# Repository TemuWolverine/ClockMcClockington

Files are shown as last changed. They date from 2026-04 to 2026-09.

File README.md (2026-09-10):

# ClockMcClockington
I currently have some “Lenovo Smart Clock Essentials” around the house, but they’ll need to be returned to the original owner soon. Essentially they’re just a segment display with some smarts and a microphone for Google Home.

I’m no fan of voice assistance, so the microphone has been off, meaning they don’t provide much real world value for me other than a clock and that should be easy enough to replicate with an ESP32 and ESPHome.

Since all of the smarts in my house run off Home Assistant (HA), I want this clock to be able to interact with HA. Specifically, I want some buttons that can then trigger other things in the house, such as “shut down all the lights”, or “volume up/down” for the bedroom Sonos speakers. That way I don’t need to have my phone on.

## BoM
| Part | Quantity | Note |
| -----| --- | ---- |
| [ESP32-S3 Nano](https://s.click.aliexpress.com/e/_c4kUQqIB) | 1 | If you're using the ClockMcClockington PCB, it is designed for this specific ESP32. Otherwise, any S3 with 2MB of PSRAM should be fine |
| [5mm Tactile switches](https://s.click.aliexpress.com/e/_c4DqcA55) | 4 | |
| [GL5516 LDR Photoresistor](https://s.click.aliexpress.com/e/_c41f2RgX) | 1 | |
| [INMP441 Microphone](https://www.aliexpress.com/item/1005006090551057.html) | 1 | |
| [MAX98357a amplifier](https://www.aliexpress.com/item/1005007003802663.html) | 1 | |
| Speaker | 1 | |
|  0.1uf ceramic capacitor | 2| Decoupling, through-hole|
| 10k ohm resistor | 1 | Through-hole|
| ClockMcClockington PCB | 1 | Optional|

## Software
The ESPHome configuration is available as the [yaml file](https://github.com/TemuWolverine/ClockMcClockington/blob/main/clock.yaml), or as a [binary you can flash directly from your browser](https://temuwolverine.github.io/ClockMcClockington/)

### Setup
The temperature information is fetched from Home Assistant. You'll need to have the sensor preconfigured.

* Setup a template sensor
* Navigate (in Home Assistant) to Settings > Devices & Services > Helpers
* Create Helper (bottom right corner) > Template > Sensor
* Two fields are required, the name and the state. Name must be `clock_temp`
* Set the state to `{{ states("sensor.myweathersensor_temperature")}}`
  The other fields are entirely optional, but can make presentation in HomeAssistant clearer 

Alternatively, you can edit the YAML, change `weatherSensor : sensor.clock_temp` to `weatherSensor : sensor.sensor.myweathersensor_temperature`

### Automations
The way ESPHome exposes hardware buttons to Home Assistant is a bit funky (or I'm an idiot and have done it wrong) - they're exposed as generic events rather than 'click'.

ClockMcClockington sends out `esphome.<name>.clock_button_pressed`, where name will start with 'clockmcclockington' plus the MAC of the device. The event data will be one, two, three or four. Currently long press and double click are not implemented. 
```yaml
alias: btnOne
description: ""
triggers:
  - trigger: event
    event_data:
      button: one
    event_type: esphome.clockmcclockingtonred.clock_button_pressed
conditions: []
actions:
  - action: light.toggle
    metadata: {}
    target:
      area_id: study
    data: {}
mode: single
```

## Shell
TODO: 

## Circuit
The Kicad project for the circuit design is available under the [/circuit](https://github.com/TemuWolverine/ClockMcClockington/tree/main/circuit) folder


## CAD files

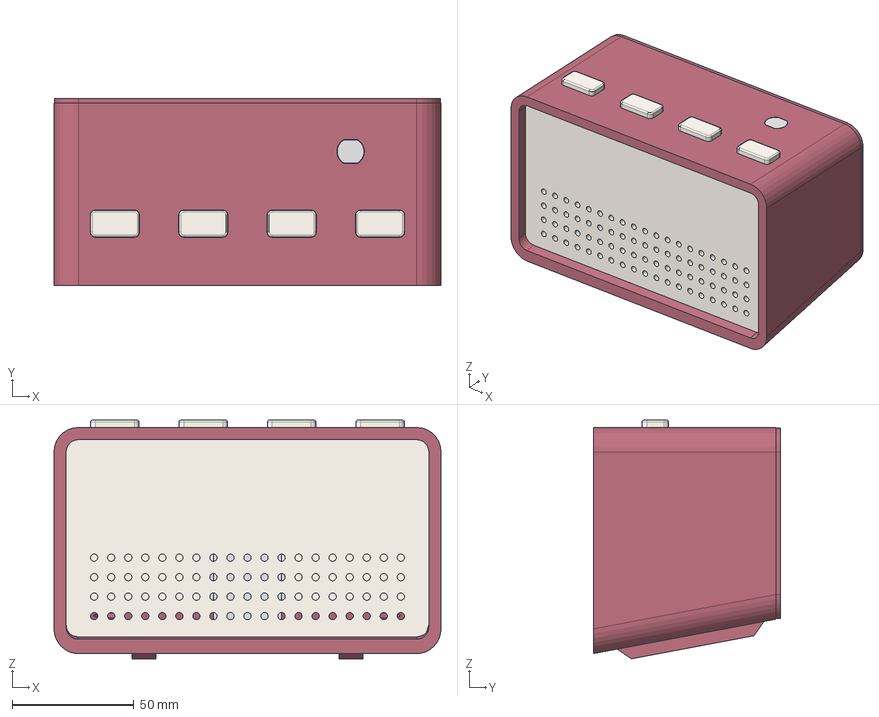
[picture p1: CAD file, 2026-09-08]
models/ClockMcClockington.step
159.0 x 77.0 x 98.0 mm
Outside
Button x 4
Back Panel
LDR Cap
Speaker
PCB
90 5xHeader Pins
1088AS x 4
8x female rounded header x 8
MAX7219--3DModel-STEP-56544 x 4
PinSocket_1x05_P2.54mm_Vertical
R_Axial_DIN0204_L3.6mm_D1.6mm_P2.54mm_Vertical
PinHeader_1x07_P2.54mm_Vertical
C_Disc_D8.0mm_W2.5mm_P5.00mm x 2
SW_PUSH_6mm_H5mm x 4
R_LDR_4.9x4.2mm_P2.54mm_Vertical
Clock_silkscreen
Clock_silkscreen_1
Clock_PCB

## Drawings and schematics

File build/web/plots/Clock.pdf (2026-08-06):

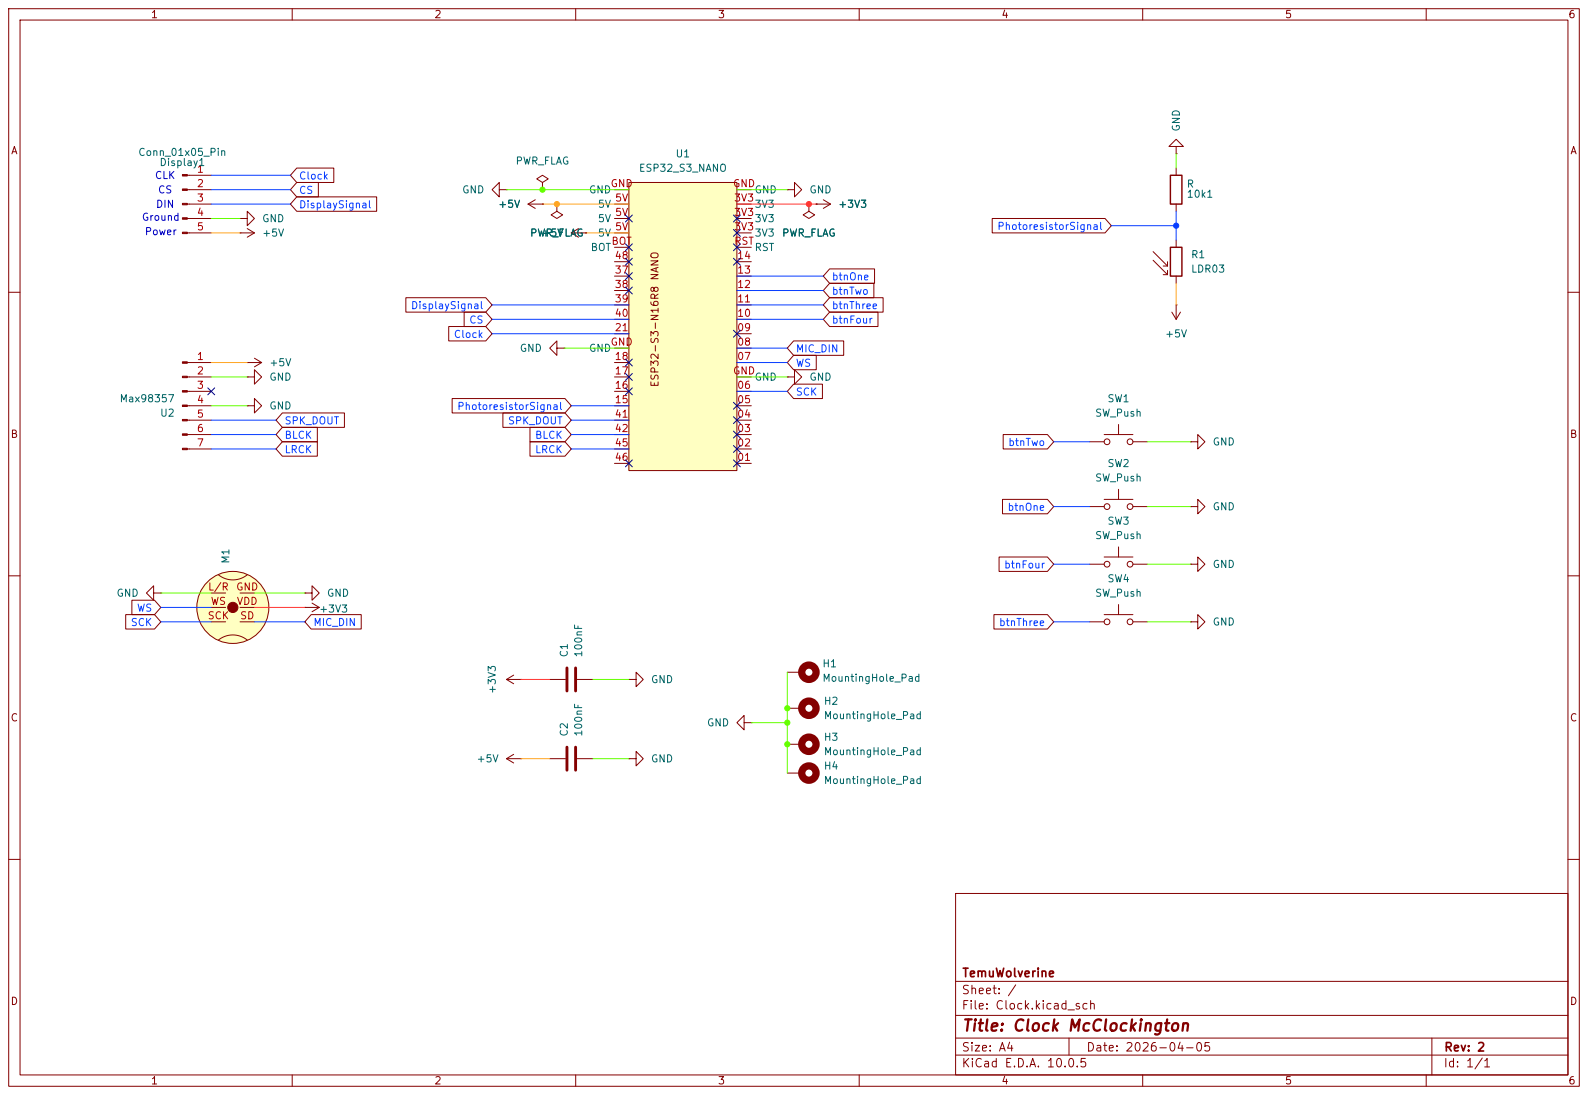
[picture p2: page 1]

Size: A4 | Rev: 2
KiCad E.D.A. 10.0.5 | Id: 1/1

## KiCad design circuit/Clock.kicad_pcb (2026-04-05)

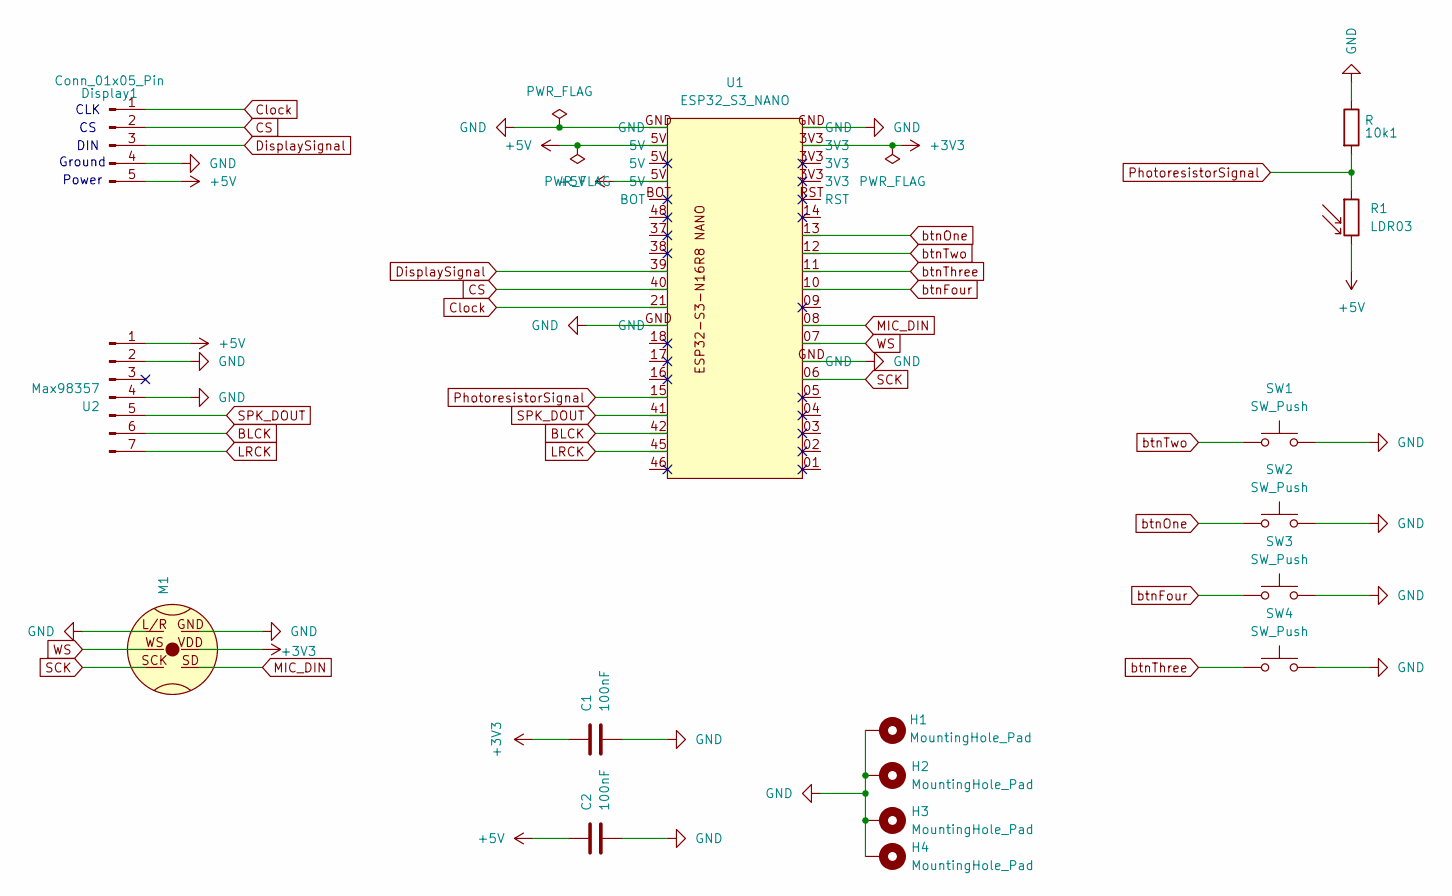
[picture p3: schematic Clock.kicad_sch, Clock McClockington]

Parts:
10k1: R; R_Axial_DIN0204_L3.6mm_D1.6mm_P2.54mm_Vertical
C1, C2: 100nF; C_Disc_D8.0mm_W2.5mm_P5.00mm
Display1: Conn_01x05_Pin; PinSocket_1x05_P2.54mm_Vertical
H1, H2, H3, H4: MountingHole_Pad; MountingHole_3.2mm_M3_Pad
M1: INMP441
R1: LDR03; R_LDR_4.9x4.2mm_P2.54mm_Vertical
SW1, SW2, SW3, SW4: SW_Push; SW_PUSH_6mm_H5mm
U1: ESP32_S3_NANO
U2: Max98357; PinHeader_1x07_P2.54mm_Vertical

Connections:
+3V3: C1.1, M1.VDD, U1.3V3
+5V: C2.1, Display1.5, R1.2, U1.5V, U2.1
BLCK: U1.42, U2.6
CS: Display1.2, U1.40
Clock: Display1.1, U1.21
DisplaySignal: Display1.3, U1.39
GND: 10k1.1, C1.2, C2.2, Display1.4, H1.1 (1_1), H2.1 (1_1), H3.1 (1_1), H4.1 (1_1), M1.GND, M1.L/R, SW1.2, SW2.2, SW3.2, SW4.2, U1.GND, U2.2, U2.4
LRCK: U1.45, U2.7
MIC_DIN: M1.SD, U1.08
PhotoresistorSignal: 10k1.2, R1.1, U1.15
SCK: M1.SCK, U1.06
SPK_DOUT: U1.41, U2.5
WS: M1.WS, U1.07
btnFour: SW3.1, U1.10
btnOne: SW2.1, U1.13
btnThree: SW4.1, U1.11
btnTwo: SW1.1, U1.12

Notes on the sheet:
CLK
Power
DIN
Ground

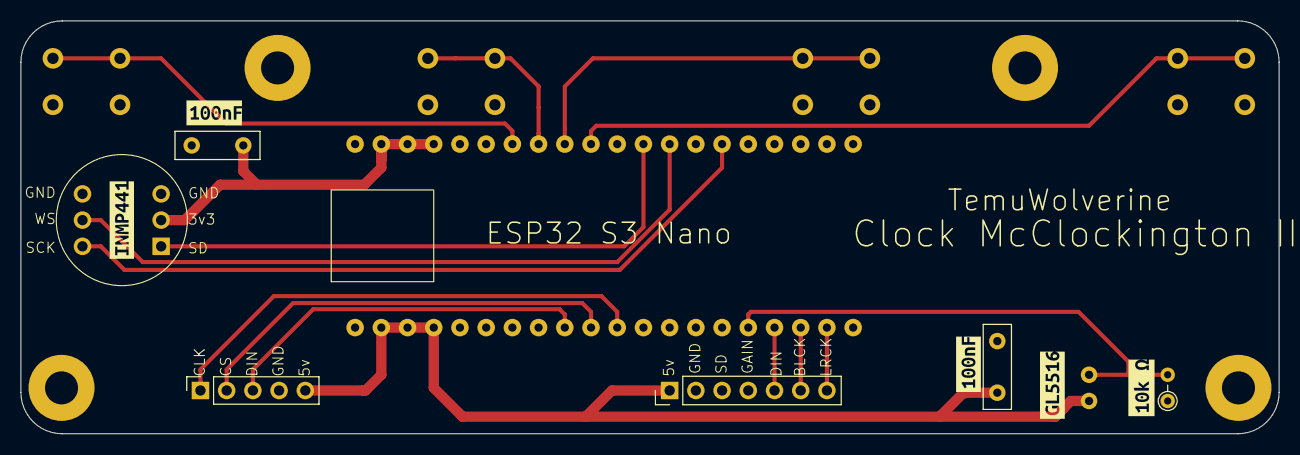
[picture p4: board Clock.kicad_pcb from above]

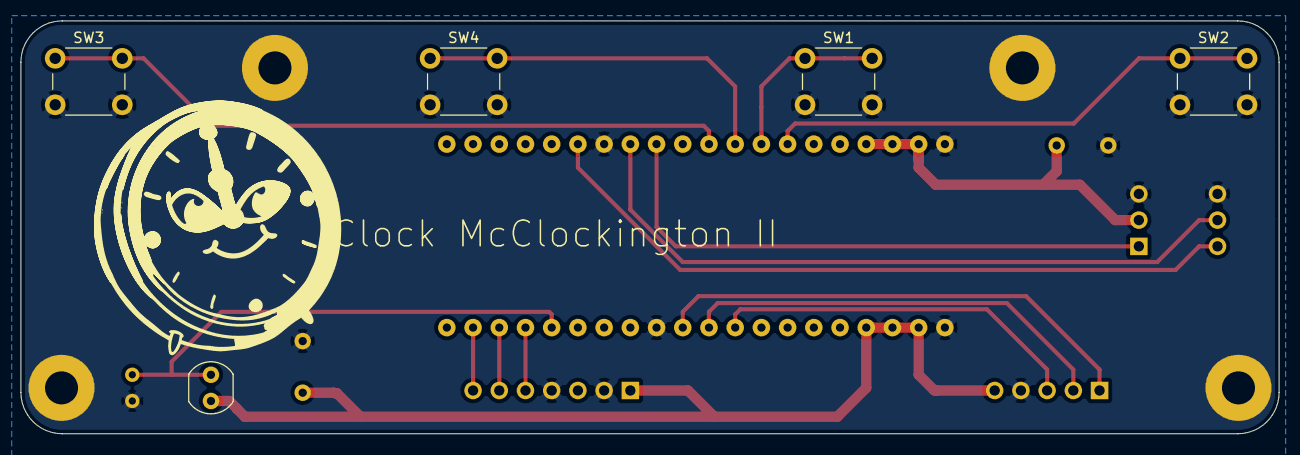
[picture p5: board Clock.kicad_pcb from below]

Board: 2 copper layers, 121.9 x 40.0 mm, 21 parts (5 on the bottom side), 17 nets.

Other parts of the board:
kibuzzard-69B74AE8: G***; kibuzzard-69B74AE8
kibuzzard-69B74AF7: G***; kibuzzard-69B74AF7
kibuzzard-69B74B07: G***; kibuzzard-69B74B07
kibuzzard-69B74B24, kibuzzard-69B74B24#2: G***; kibuzzard-69B74B24

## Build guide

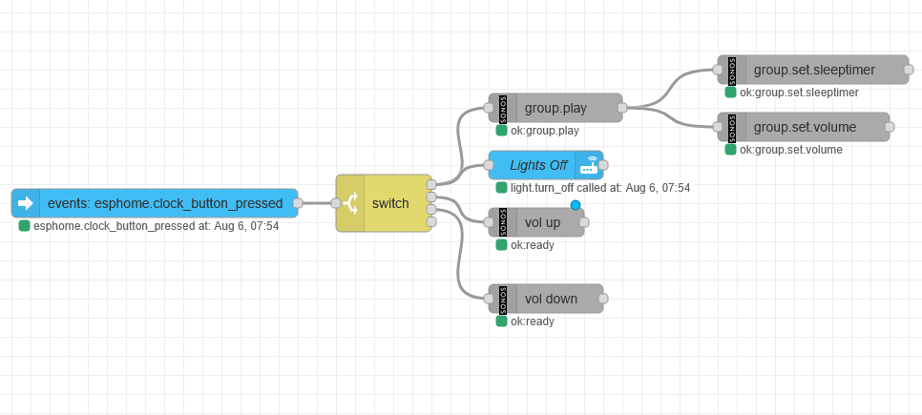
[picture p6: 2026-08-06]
build/web/assets/images/nodered.png

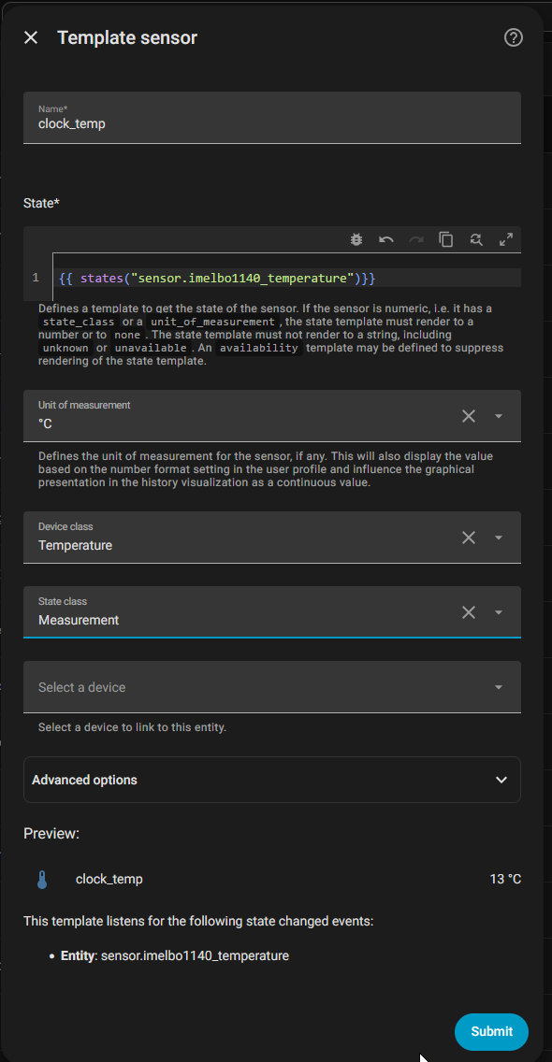
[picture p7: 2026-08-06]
build/web/assets/images/firefox_DwW2C3pwxb.png

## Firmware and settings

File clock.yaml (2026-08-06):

# ESPHome "Take Control" does not like yaml frontmatter.
# author: Paul Jenkins
# name: ClockMcClockington
# version: 0.1
# source: https://github.com/TemuWolverine/ClockMcClockington
# labels: [clock, led matrix, esp32]
# ---

substitutions:
  friendly_name: ClockMcClockington
  device_name: clockmcclockington
  weatherSensor : sensor.clock_temp

  #Sound pins (I2S)
  speaker_i2s_lrclk_pin: GPIO45 #WS
  speaker_i2s_bclk_pin: GPIO42 #SCK
  speaker_i2s_dout_pin : GPIO41 #DIN

  mic_i2s_ws_pin: GPIO7 #lrclk
  mic_i2s_sck_pin: GPIO6 #bclk
  mic_i2s_din_pin : GPIO8  #SD

  #Display pins (I2C)
  mosiPin : GPIO39
  csPin : GPIO40
  clkPin :  GPIO21

  #light sensor pin
  ldr_pin: GPIO15
  
  #button pins
  button_one: GPIO13
  button_two: GPIO12
  button_three: GPIO11
  button_four: GPIO10

  mediaplayer: "speakerguy"
  i2s_microphone: "i2s_microphone"

packages:
  esphome_templates:
    url: https://github.com/TemuWolverine/esphome_templates
    ref: main
    refresh: 1s
    files:
      - boards/esp32_s3_nano.yaml
      - devices/i2s/INMP441.yaml
      - devices/i2s/MAX98357.yaml
      - devices/display/max7219.yaml

  clockmcclockington:
    url: https://github.com/TemuWolverine/ClockMcClockington
    ref: main
    files:
      - shared.yaml
esphome:
  name: ${device_name}
  friendly_name: ${friendly_name}
  name_add_mac_suffix: true


esp32:
  variant: ESP32S3
  framework:
    type: esp-idf

psram:
  mode: octal

# To be able to get logs from the device via serial and api.
logger:

# API is a requirement of the dashboard import.
api:

# OTA is required for Over-the-Air updating
ota:
  - platform: esphome

wifi:
  # Set up a wifi access point using the device name above
  ap:

# In combination with the `ap` this allows the user
# to provision wifi credentials to the device.
captive_portal:

web_server:
  version: 3
  
#global config
globals:
  - id: startup_complete
    type: bool
    initial_value: 'false'

  - id: brightness_dark_cfg
    type: int
    restore_value: yes
    initial_value: '0'

  - id: brightness_dim_cfg
    type: int
    restore_value: yes
    initial_value: '5'

  - id: brightness_mid_cfg
    type: int
    restore_value: yes
    initial_value: '10'

  - id: brightness_bright_cfg
    type: int
    restore_value: yes
    initial_value: '15'

number:
  - platform: template
    name: "1. Dark"
    id: ldr_brightness_dark
    min_value: 0
    max_value: 15
    lambda: 'return (float) id(brightness_dark_cfg);'
    step: 1
    set_action:
      - globals.set:
          id: brightness_dark_cfg
          value: !lambda 'return (int) x;'

  - platform: template
    name: "2. Dim"
    id: ldr_brightness_dim
    min_value: 0
    max_value: 15
    step: 1
    lambda: 'return (float) id(brightness_dim_cfg);'
    set_action:
      - globals.set:
          id: brightness_dim_cfg
          value: !lambda 'return (int) x;'

  - platform: template
    name: "3. Mid"
    id: ldr_brightness_mid
    min_value: 0
    max_value: 15
    step: 1
    lambda: 'return (float) id(brightness_mid_cfg);'
    set_action:
      - globals.set:
          id: brightness_mid_cfg
          value: !lambda 'return (int) x;'

  - platform: template
    name: "4. Bright"
    id: ldr_brightness_bright
    min_value: 0
    max_value: 15
    step: 1
    lambda: 'return (float) id(brightness_bright_cfg);'
    set_action:
      - globals.set:
          id: brightness_bright_cfg
          value: !lambda 'return (int) x;'


binary_sensor:
  - platform: gpio
    pin:
      number: ${button_one}
      mode:
        input: true
        pullup: true
    id: btnOne
    internal: True
    name: "Clock Button One"
    on_press:
      then:
        - homeassistant.event:
            event: esphome.${device_name}.clock_button_pressed
            data: { button: "one", type: "single" }

  - platform: gpio
    pin:
      number: ${button_two}
      mode:
        input: true
        pullup: true
    id: btnTwo
    internal: True
    name: "Clock Button Two"
    on_press:
      then:
        - homeassistant.event:
            event: esphome.${device_name}.clock_button_pressed
            data: { button: "two", type: "single" }

  - platform: gpio
    pin:
      number: ${button_three}
      mode:
        input: true
        pullup: true
    id: btnThree
    name: "Clock Button Three"
    internal: True
    on_press:
      then:
        - homeassistant.event:
            event: esphome.${device_name}.clock_button_pressed
            data: { button: "three", type: "single" }

  - platform: gpio
    pin:
      number: ${button_four}
      mode:
        input: true
        pullup: true
    id: btnFour
    name: "Clock Button Four"
    internal: True
    on_press:
      then:
        - homeassistant.event:
            event: esphome.${device_name}.clock_button_pressed
            data: { button: "four", type: "single" }
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

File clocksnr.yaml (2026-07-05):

author: Paul Jenkins
name: ClockMcClockington Senior
version: 0.1
source: https://github.com/TemuWolverine/ClockMcClockington
labels: [clock, led matrix, esp32, ws2815]
---

substitutions:
  friendly_name: ClockMcClockingtonSnr
  device_name: clockmcclockington-snr
  weatherSensor : sensor.imelbo1140_temperature

packages:
  esphome_templates:
    url: https://github.com/TemuWolverine/esphome_templates
    ref: main
    files:
      - esphome_boilerplate.yaml
#      - devices/ldr-GL5516.yaml

  clockmcclockington:
    url: https://github.com/TemuWolverine/ClockMcClockington
    ref: main
    refresh: 20s
    files:
      - shared.yaml

esp32:
  variant: esp32
  framework:
    type: esp-idf
   
number:
  - platform: template
    name: "Clock Brightness Override"
    id: clock_brightness_override
    internal: false
    max_value: 100
    min_value: 15
    step: 5
    optimistic: true
    mode: slider
    on_value:
      then:
        - globals.set: 
            id: brightness
            value : !lambda "return x;"

light:
  - platform: esp32_rmt_led_strip
    rgb_order: GRB
    pin: GPIO2
    num_leds: 257
    chipset: ws2812
    id: led_matrix_light   

display:
  - platform: addressable_light
    id: led_matrix_display
    addressable_light_id: led_matrix_light
    width: 32
    height: 9

    rotation: 0°
    update_interval: 2s
    pixel_mapper: |-
      int num=0;
      if (y % 2 == 0) {
        num = (y * 32) + x;
      } else {
        num =  (y * 32) + (31 - x);
      }

      return num +1;
    lambda: |-
        static bool clock_should_blink = true;

        int maxbright = (int)((id(brightness)/100.0) * 255);
        auto time_str = id(hass_time).now().strftime("%a");//this needs to sit outside the switch
        auto white = Color(maxbright, maxbright, maxbright);
        Color green = Color(0, maxbright, 0);
        
        //Calculate 12-hour format hour and its text width for right-alignment
        int hour12 = id(hass_time).now().hour % 12 == 0 ? 12 : id(hass_time).now().hour % 12;
        char hour_str[3];
        sprintf(hour_str, "%d", hour12);
        int text_width, text_height, x_offset, y_offset;
        it.get_text_bounds(0, 0, hour_str, id(TimeFont),  TextAlign::TOP_LEFT, &x_offset, &y_offset, &text_width, &text_height);

        //print the time
        it.print(23 - text_width, 0, id(TimeFont),  white, hour_str);
        it.strftime(25, 0, id(TimeFont), white, "%M",   id(hass_time).now());

        if (clock_should_blink) {
          it.print(23, 0, id(TimeFont),  white, ":");
        }

        switch (id(page))
        {
          case 1: //Day
            std::transform(time_str.begin(), time_str.end(), time_str.begin(), ::toupper);
            it.print(0, 2, id(DayFont), white, time_str.c_str());
            it.line(0, 0, 13, 0, white);
            
            break;

          case 2: //Temperature
            it.printf(0, 0, id(DayFont),  green, "%g°", id(outside_temp).state);
            it.line(0, 7, 9, 7, white);
            break;
        }

        clock_should_blink = !clock_should_blink;

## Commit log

2026-01-16 updated to be gooderer
    [Clock.kicad_pcb, Clock.kicad_sch]
2026-01-24 rev 1.0 of pcb
    [Clock.kicad_pcb, Clock.kicad_sch]
2026-02-03 Update Clock PCB nets & footprints
    [Clock.kicad_pcb, Clock.kicad_sch]
2026-02-03 updated pcb
    [Clock.kicad_pcb, Clock.kicad_sch]
2026-03-12 ESPHome config now works - needed two I2S channels for input/output. Updated circuit design to reflect this, and better designed PCB/layout with updated ESPS3-zero footprint/symbol
    [Clock.kicad_pcb, Clock.kicad_sch]
2026-03-13 more tweaks
    [Clock.kicad_pcb, Clock.kicad_sch]
2026-03-14 switched to mom-switches rather than ttp223 capacitive sensors
    [Clock.kicad_pcb, Clock.kicad_sch]
2026-03-18 fully functional based on breadboard prototype
    [Clock.kicad_pcb, Clock.kicad_sch]
2026-04-05 design sent to mfg
    [Clock.kicad_pcb, Clock.kicad_sch]
2026-06-19 forgot the sensor
2026-07-05 Fixes for big guys missing pixels
    [clocksnr.yaml]
2026-09-08 Cleaned up soem HTML, added STEP model
    [ClockMcClockington.step]
